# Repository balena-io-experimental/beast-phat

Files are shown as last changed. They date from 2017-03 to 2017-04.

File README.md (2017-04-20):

# Beast power pHAT

This board is designed to supply power to each Raspberry Pi (RPi) on a [Beast](https://resin.io/blog/the-evolution-of-the-beast-continues/
) tile with a [daisy chain](https://en.wikipedia.org/wiki/Daisy_chain_(electrical_engineering)) topology to reduce the complexity of cabling. It connects to each RPi through its GPIO header, exposing all the pins with a stacking header to allow another HAT attached on top.

In this first iteration, the board needs a 24V@10A power supply so it can be daisy chained to up to 12 RPis. The final version is expected to allow an input voltage range from 12V to 24V.

The only manufacturing constrain of this board is that it needs 2oz or higher copper weight.

Raspberry Pi HAT outline taken from [here](https://github.com/xesscorp/RPi_Hat_Template) and inductor footprint from [here](https://github.com/Tinkerforge/kicad-libraries/blob/master/SRN6045.kicad_mod).

This project was designed with [KiCad](http://kicad-pcb.org/) open source EDA suite.

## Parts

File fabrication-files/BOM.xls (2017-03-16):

 | Bill of Materials (BOM)
Item # | Ref Des | Qty | Manufacturer | Mfg Part # | Description | Package | Type | Your Instructions
1 | C3 | 1 | Kemet | C0805C104K5RACTU | CAP CER 0.1UF 50V X7R 0805 | 805 | SMD
2 | C1 | 1 | TDK | C1608X5R1V475K080AC | CAP CER 4.7UF 35V X5R 0603 | 603 | SMD
3 | C5 | 1 | TDK | C2012X5R1A476M125AC | CAP CER 47UF 10V X5R 0805 | 805 | SMD
4 | C2 | 1 | MuRata | GRM155R71C822KA01D | CAP CER 8200PF 16V X7R 0402 | 402 | SMD
5 | D3 | 1 | Comchip Technology | CDBC540-G | DIODE SCHOTTKY 40V 5A DO214AB | SMC | SMD
6 | L1 | 1 | Bourns | SRN6045TA-3R3Y | FIXED IND 3.3UH 5A 21 MOHM SMD | Custom | SMD
7 | R5 | 1 | Yageo America | RC0603FR-0712KL | RES SMD 12K OHM 1% 1/10W 0603 | 603 | SMD
8 | R4 | 1 | Yageo America | RC0603FR-0768KL | RES SMD 68K OHM 1% 1/10W 0603 | 603 | SMD
9 | R3 | 1 | Vishay-Dale | CRCW040220K0FKED | RES SMD 20K OHM 1% 1/16W 0402 | 402 | SMD
10 | U1 | 1 | Texas Instruments | LMR14030SDDAR | IC REG BUCK ADJ 3.5A | HSOIC-8 | SMD
11 | C4 | 1 | Kemet | C0805C121J5GACTU | CAP CER 120PF 50V NP0 0805 | 805 | SMD
12 | P1,P2 | 2 | Phoenix Contact | 1869363 | CONN TERM BLOCK 2POS 3.81MM | Custom | Through-hole
13 | P3 | 1 | NKK Switches | M2013SS1W01 | SWITCH TOGGLE SPDT 6A 125V | Custom | Through-hole | Oval drill holes
14 | P4 | 1 | Generic | Pimoroni’s COM0002 | 2x20 pin GPIO Header for Raspberry Pi 3 | 40 pos | Through-hole | Extra long 11mm, with female header on top: https://shop.pimoroni.com/products/2x20-pin-gpio-header-for-raspberry-pi-2-b-a
15 | D2 | 1 | Osram | LG Q396-PS-35 | LED GREEN DIFFUSED 0603 SMD | 603 | SMD
16 | D1 | 1 | Osram | LR Q396-P1Q2-1 | LED RED DIFFUSED 0603 SMD | 603 | SMD
17 | R1,R2 | 2 | Vishay-Dale | CRCW040290K9FKED | RES SMD 90.9K OHM 1% 1/16W 0402 | 402 | SMD

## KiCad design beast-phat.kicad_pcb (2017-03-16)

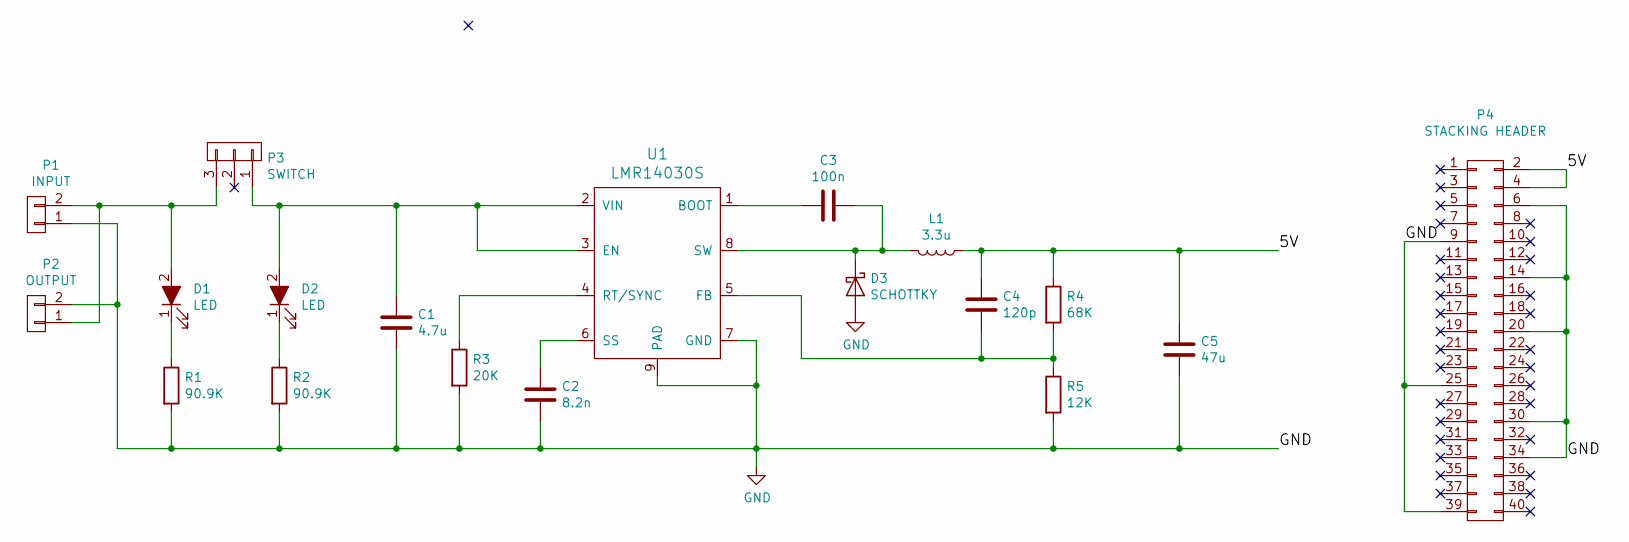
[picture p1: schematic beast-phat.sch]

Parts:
C1: 4.7u; C_0603
C2: 8.2n; C_0402
C3: 100n; C_0805
C4: 120p; C_0805
C5: 47u; C_0805
D1, D2: LED; LED_0603
D3: SCHOTTKY; D_SMC_Standard
L1: 3.3u; SRN6045
P1: INPUT; PhoenixContact_MCV-G_02x3.81mm_Vertical
P2: OUTPUT; PhoenixContact_MCV-G_02x3.81mm_Vertical
P3: SWITCH; switch
P4: STACKING HEADER; Pin_Header_Straight_2x20_Pitch2.54mm
R1, R2: 90.9K; R_0402
R3: 20K; R_0402
R4: 68K; R_0603
R5: 12K; R_0603
U1: LMR14030S; HSOP8

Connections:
/5V: C4.2, C5.2, L1.1, P4.2, P4.4, R4.1
GND: C1.1, C2.1, C5.1, D3.2 (A), P1.1, P2.2, P4.6, P4.9, P4.14, P4.20, P4.25, P4.30, P4.34, P4.39, R1.2, R2.2, R3.2, R5.2, U1.7 (GND), U1.9 (PAD)
unnamed: C1.2, D2.2 (A), P3.1, U1.2 (VIN), U1.3 (EN)
unnamed: C2.2, U1.6 (SS)
unnamed: C3.1, D3.1 (K), L1.2, U1.8 (SW)
unnamed: C3.2, U1.1 (BOOT)
unnamed: C4.1, R4.2, R5.1, U1.5 (FB)
unnamed: D1.1 (K), R1.1
unnamed: D1.2 (A), P1.2, P2.1, P3.3
unnamed: D2.1 (K), R2.1
unnamed: R3.1, U1.4 (RT/SYNC)

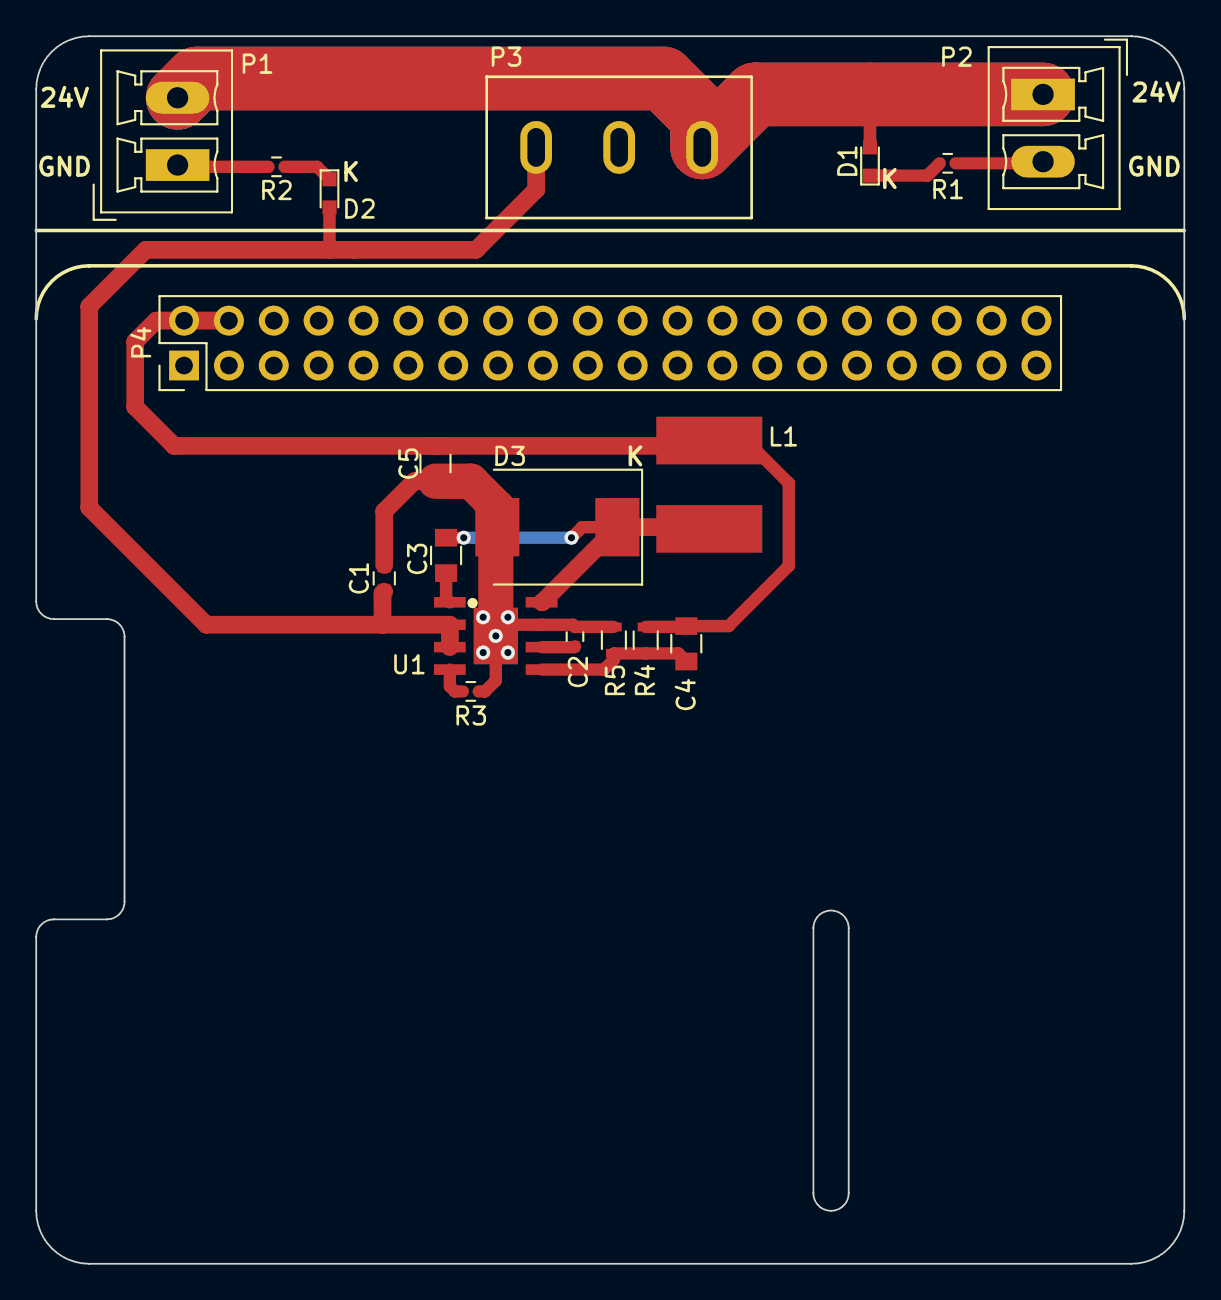
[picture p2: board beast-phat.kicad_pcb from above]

Board: 2 copper layers, 65.0 x 69.5 mm, 19 parts (0 on the bottom side), 11 nets.

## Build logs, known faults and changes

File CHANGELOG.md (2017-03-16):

Change log
-----------

* Initial commit [Tomás]
